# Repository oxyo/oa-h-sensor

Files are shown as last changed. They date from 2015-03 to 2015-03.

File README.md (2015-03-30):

# Open Automation humidity sensor   



This is an Arduino UNO compatible device with HIH5031 humidity sensor installed.  
It uses [Ciseco XRF wireless RF radio UART serial data module][] to communicate with Open Automation Center

This simple device can measure air humidity up to 3% precision. Also provided option to connect SHARP GP2Y1010AU0F dust sensor to measure the dust concentration in air.
  
Arduino firmware, schematics and board files provided. 
  
For more information please visit [openautomation.center](http://openautomation.center)

Licensed under [WTFPL license terms](http://www.wtfpl.net/)

[Ciseco XRF wireless RF radio UART serial data module]: http://shop.ciseco.co.uk/xrf-wireless-rf-radio-uart-serial-data-module-xbee-shaped/

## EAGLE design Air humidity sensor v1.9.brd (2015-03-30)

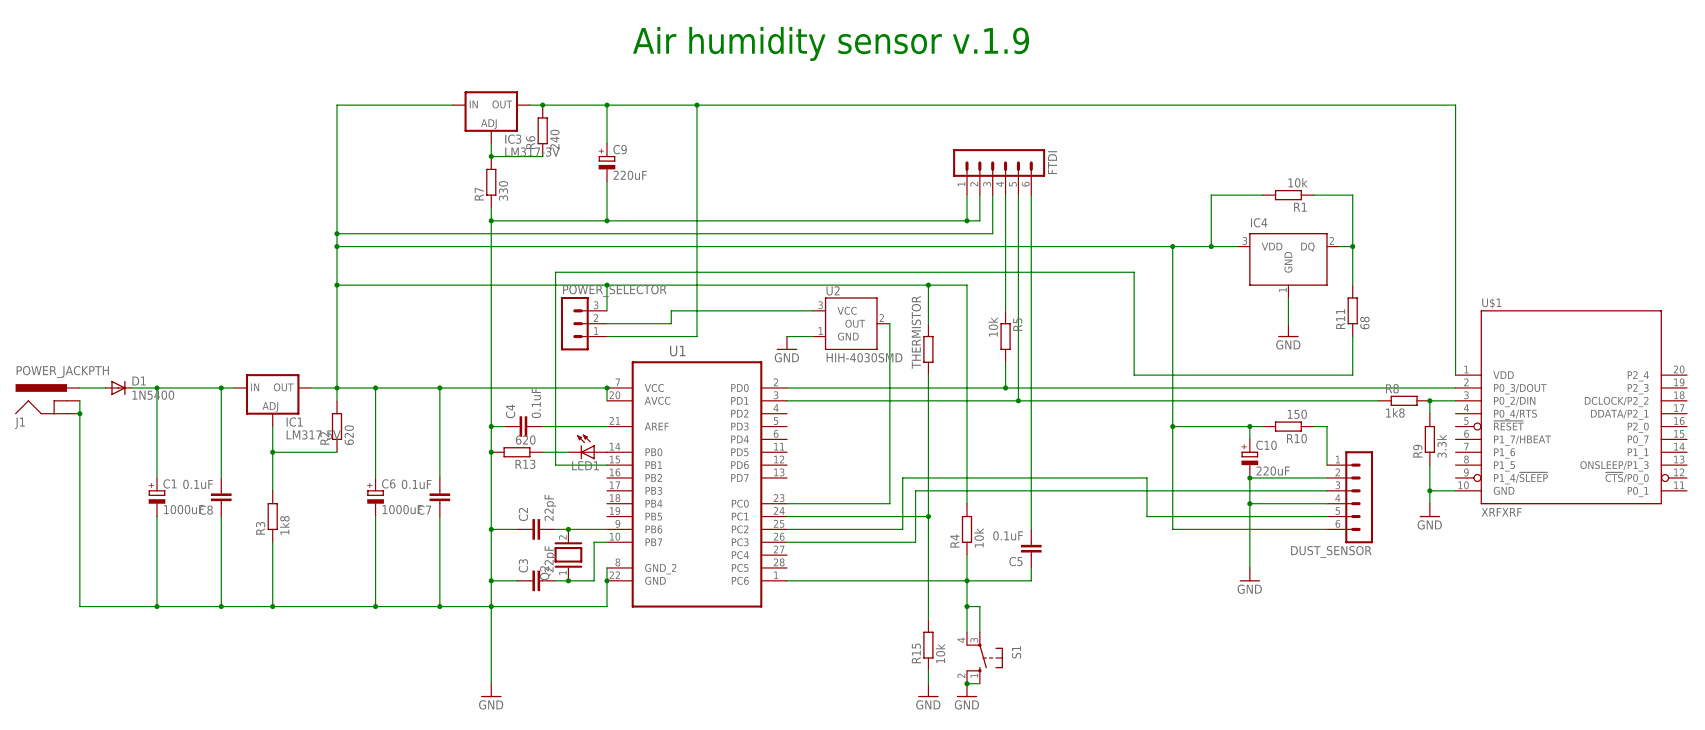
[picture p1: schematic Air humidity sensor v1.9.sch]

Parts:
C1, C6: 1000uF; E5-10,5
C2, C3: 22pF; C025-025X050
C4: 0.1uF; C075-032X103
C5, C7, C8: 0.1uF; C050-025X075
C9: 220uF; E3,5-8
C10: 220uF; E5-10,5
D1: 1N5400; DO201-15
DUST_SENSOR: MA06-1
FTDI: MA06-1
IC1: LM317 5V; 317TS
IC3: LM317-3V; 317TS
IC4: DS1820; TO-92
J1: POWER_JACKPTH; POWER_JACK_PTH
LED1: LED3MM
POWER_SELECTOR: MA03-1
Q2: XTAL/S; QS
R1, R4, R5, R15: 10k; 0207/5V
R2: 620; 0207/5V
R3: 1k8; 0207/5V
R6: 240; 0207/5V
R7: 330; 0207/5V
R8: 1k8; 0207/12
R9: 3.3k; 0207/12
R10: 150; 0207/5V
R11: 68; 0207/12
R13: 620; 0207/12
S1: 10-XX; B3F-10XX
THERMISTOR: R-EU_0207/5V; 0207/5V
U1: ATMEGA328P-PU; DIP254P762X457-28
U2: HIH-4030SMD; HIH-4030
U$1: XRFXRF; XRF

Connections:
GND: C1.-, C2.1, C3.1, C4.1, C6.-, C7.1, C8.1, C9.-, C10.-, DUST_SENSOR.2, DUST_SENSOR.4, FTDI.1, FTDI.2, IC4.1 (GND), J1.GND, J1.GNDBREAK, R3.1, R7.1, R9.1, R13.2, R15.1, S1.1 (S), S1.2 (S1), U1.8 (GND_2), U1.22 (GND), U2.1 (GND), U$1.10 (GND)
LM317-5V: IC1.1 (ADJ), R2.1, R3.2
unnamed: C4.2, U1.21 (AREF)
unnamed: C5.2, FTDI.6
unnamed: DUST_SENSOR.5, U1.25 (PC2)
unnamed: DUST_SENSOR.3, U1.26 (PC3)
unnamed: R15.2, THERMISTOR.1, U1.24 (PC1)
unnamed: C9.+, IC3.2 (OUT), POWER_SELECTOR.1, R6.2, U$1.1 (VDD)
unnamed: C6.+, C7.2, C10.+, DUST_SENSOR.6, FTDI.3, IC1.2 (OUT), IC3.3 (IN), IC4.3 (VDD), POWER_SELECTOR.3, R1.2, R2.2, R4.2, R10.2, THERMISTOR.2, U1.7 (VCC), U1.20 (AVCC)
unnamed: D1.A, J1.PWR
unnamed: U1.23 (PC0), U2.2 (OUT)
unnamed: C1.+, C8.2, D1.C, IC1.3 (IN)
unnamed: C2.2, Q2.2, U1.9 (PB6)
unnamed: C3.2, Q2.1, U1.10 (PB7)
unnamed: C5.1, R4.1, S1.3, S1.4 (P1), U1.1 (PC6)
unnamed: FTDI.4, R5.1
unnamed: R5.2, U1.2 (PD0), U$1.2 (P0_3/DOUT)
unnamed: FTDI.5, R8.1, U1.3 (PD1)
unnamed: IC3.1 (ADJ), R6.1, R7.2
unnamed: R8.2, R9.2, U$1.3 (P0_2/DIN)
unnamed: POWER_SELECTOR.2, U2.3 (VCC)
unnamed: IC4.2 (DQ), R1.1, R11.2
unnamed: R11.1, U1.15 (PB1)
unnamed: DUST_SENSOR.1, R10.1
unnamed: LED1.K (C), R13.1
unnamed: LED1.A, U1.14 (PB0)

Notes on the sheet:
Air humidity sensor v.1.9

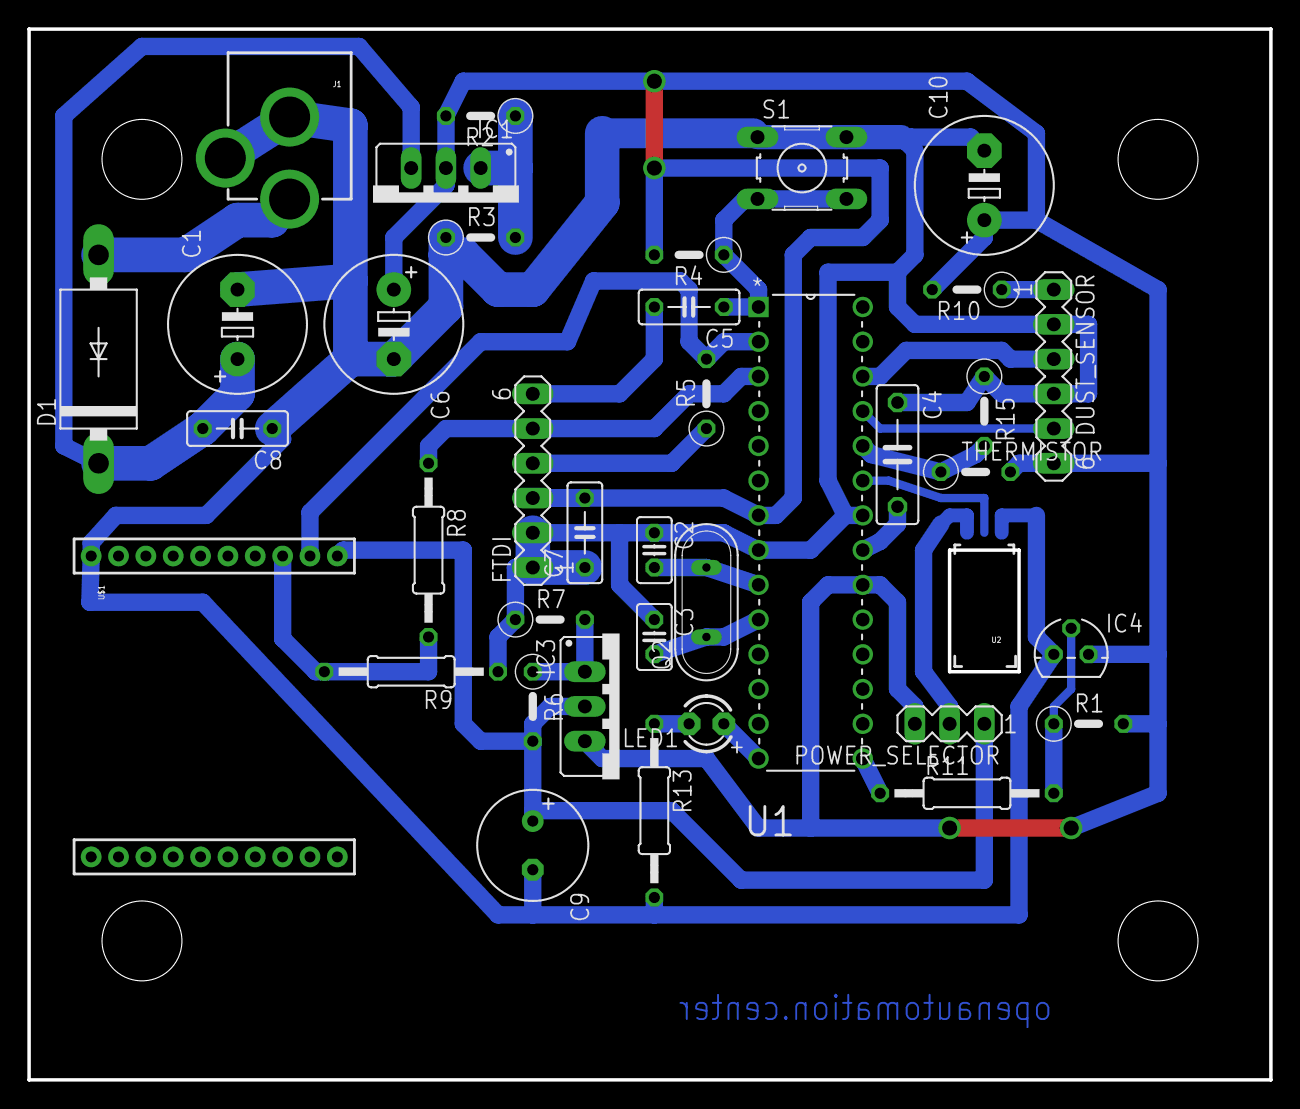
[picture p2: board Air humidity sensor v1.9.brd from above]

Board: 2 copper layers, 90.8 x 76.8 mm, 38 parts (0 on the bottom side), 26 nets.

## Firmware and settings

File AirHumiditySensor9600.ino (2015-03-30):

/*
 * Air hummidity and dust sensor code by V.Gudaitis oxyo@smartsensors.lt
 * Version 1.2
 * 
 * HARDWARE
 * SENSORS: Hummidity - HIH5031; Temperature - DS18B20; Dust - Sharp GP2Y1010AU0F.
 * 
 * Library used:
 * Andrew Bythell <abythell@ieee.org> HIH4030 sensor Library
 * https://github.com/angryelectron/tweetpot/tree/master/arduino/HIH4030
 *
 * Dust sensor code from:
 * http://itp.nyu.edu/physcomp/sensors/Reports/GP2Y1010AU
 *
 */

#include <OneWire.h>
#include <DallasTemperature.h>
#include <HIH4030.h>

#define LED 8
#define ONE_WIRE_BUS 9		
#define HIH4030_PIN A0
#define HIH4030_SUPPLY_VOLTAGE  5.0

/*
 * Set the analog reference voltage.  Unless you have set it explicity using
 * analogReference(), this will be the same voltage as your Arduino, either 3.3 or 5.0
 */
#define ARDUINO_VCC 5.0

/*
 * Set Factory Calibration Values, if available.  Here we'll use the values from
 * the datasheet's Table 2: Example Data Printout
 */
#define SLOPE 0.03068
#define OFFSET 0.958

// Global variables
OneWire oneWire(ONE_WIRE_BUS);
DallasTemperature sensors(&oneWire);
DeviceAddress thermometer;
HIH4030 uncalibratedHygrometer(HIH4030_PIN, HIH4030_SUPPLY_VOLTAGE, ARDUINO_VCC);
HIH4030 calibratedHygrometer(HIH4030_PIN, HIH4030_SUPPLY_VOLTAGE, ARDUINO_VCC);

//Dust sensor setup
int dustPin=A2;
int dustVal=0;
int dustLedPower=A3;
int delayTime=280;
int delayTime2=60;
float offTime=9680;

void setup(void)
{
  pinMode(dustLedPower,OUTPUT);
  pinMode(LED,OUTPUT);  
  digitalWrite(LED,LOW); //Disable heartbeat LED
  digitalWrite(dustLedPower,HIGH); //Disable dust sensor LED

  Serial.begin(9600);
  delay(1000);

  sensors.begin();
  if (!sensors.getAddress(thermometer, 0)) Serial.println("Unable to find DS18B20"); 

  calibratedHygrometer.calibrate(SLOPE, OFFSET);
}

void loop(void)
{ 
  blinkLED();
  
  //Get DS18B20 temperature value  
  sensors.requestTemperatures(); 
  delay(1000);
  
  printHummidityValue();
  blinkLED(); 

 
}

//FUNCTIONS ====================================================

//MCU heartbeat indication 
void blinkLED(){
 digitalWrite(LED,HIGH);  
 delay(100);
 digitalWrite(LED,LOW); 
 delay(100);
 digitalWrite(LED,HIGH);  
 delay(100);
 digitalWrite(LED,LOW); 
 delay(100);
}


//Debug print all hummidity parameters
void printHummidityData(HIH4030 hygrometer, float temperature) {
  Serial.print("T = ");
  Serial.print(temperature);
  Serial.print("C V = ");
  Serial.print(hygrometer.vout());
  Serial.print("V RH = ");
  Serial.print(hygrometer.getSensorRH());
  Serial.print("% CRH = ");
  Serial.print(hygrometer.getTrueRH(temperature));
  Serial.println("%");
}

//Measure calibrated temperature compensated RH
void hValue(HIH4030 hygrometer, float temperature) { 
  Serial.print(hygrometer.getTrueRH(temperature) + 15);
}

//Print hummidity value
void printHummidityValue() {
  float temperature;
  temperature = sensors.getTempC(thermometer);
  //Serial.print("Uncalibrated: ");
  //printHummidityData(uncalibratedHygrometer, temperature); 
  Serial.print("aH0CRHP");
  hValue(calibratedHygrometer, temperature); 
  Serial.println(); 
  //delay(4000);
  //Serial.print("aT0TMPA");
  //Serial.print(temperature);  
  delay(59000);  
}

//Print air dust concentration value
void printDustValue(){  
  digitalWrite(dustLedPower,LOW); // power on the dust sensor LED
  delayMicroseconds(delayTime);
  dustVal=analogRead(dustPin); // read the dust value
  delayMicroseconds(delayTime2);
  digitalWrite(dustLedPower,HIGH); // turn the dust sensor LED off
  delayMicroseconds(offTime);
  //delay(1000);
  if (dustVal < 10){
    Serial.print("aD0DVAL0.00");
  } else if (dustVal < 100){
    Serial.print("aD0DVAL0.0");
  } else {  
    Serial.print("aD0DVAL0.");
  }
  Serial.print(dustVal);
}

//Measure V supply for precise ADC conversions
long readVcc() { 
  long result; // Read 1.1V reference against AVcc 
  ADMUX = _BV(REFS0) | _BV(MUX3) | _BV(MUX2) | _BV(MUX1); 
  delay(2); // Wait for Vref to settle 
  ADCSRA |= _BV(ADSC); // Convert
  while (bit_is_set(ADCSRA,ADSC)); 
  result = ADCL; 
  result |= ADCH<<8; 
  result = 1125300L / result; // Back-calculate AVcc in mV 
  return result; 
} 

//Print VCC value
void printVCC(){
  Serial.print(" VCC:"); 
  Serial.print( readVcc(), DEC ); 
  Serial.println();
}

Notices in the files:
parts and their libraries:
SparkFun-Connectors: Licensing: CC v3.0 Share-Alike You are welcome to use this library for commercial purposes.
